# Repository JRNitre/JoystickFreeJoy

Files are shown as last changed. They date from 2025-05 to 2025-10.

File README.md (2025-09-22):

# JoystickFreeJoy

*基于 FreeJoy 固件的高精度双轴霍尔传感器 USB-HID 低成本 3D 打印摇杆方案*

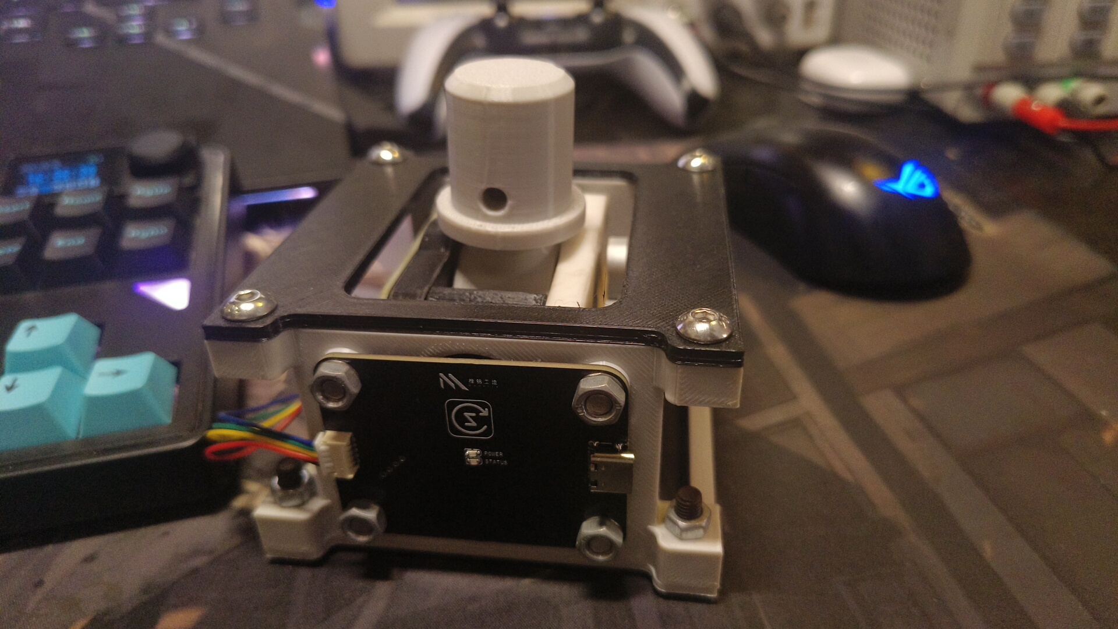
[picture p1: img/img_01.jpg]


兼顾低成本和高精度的 3D 打印摇杆方案。

# 项目特点

- 开源设计：本项目基于 MIT 协议开源，鼓励用户贡献或改进。
- 低成本：机械结构部分采用 3D 打印组件，便于制造和自定义生产。
- USB-HID：无需驱动即可实现游戏输入设备的模拟，即插即用。
- 高精度霍尔传感器：使用基于 SPI 通讯的高精度霍尔传感器 TLE5012BE100

# 许可证

本项目采用 MIT 许可证。有关详细条款，请参阅 LICENSE 文件。

# 源项目地址

本项目使用的固件和结构基于如下开源项目修改而来。

- **FreeJoy**：https://github.com/FreeJoy-Team/FreeJoy
- **底座机械结构**：https://www.thingiverse.com/thing:2496028

# 五金件

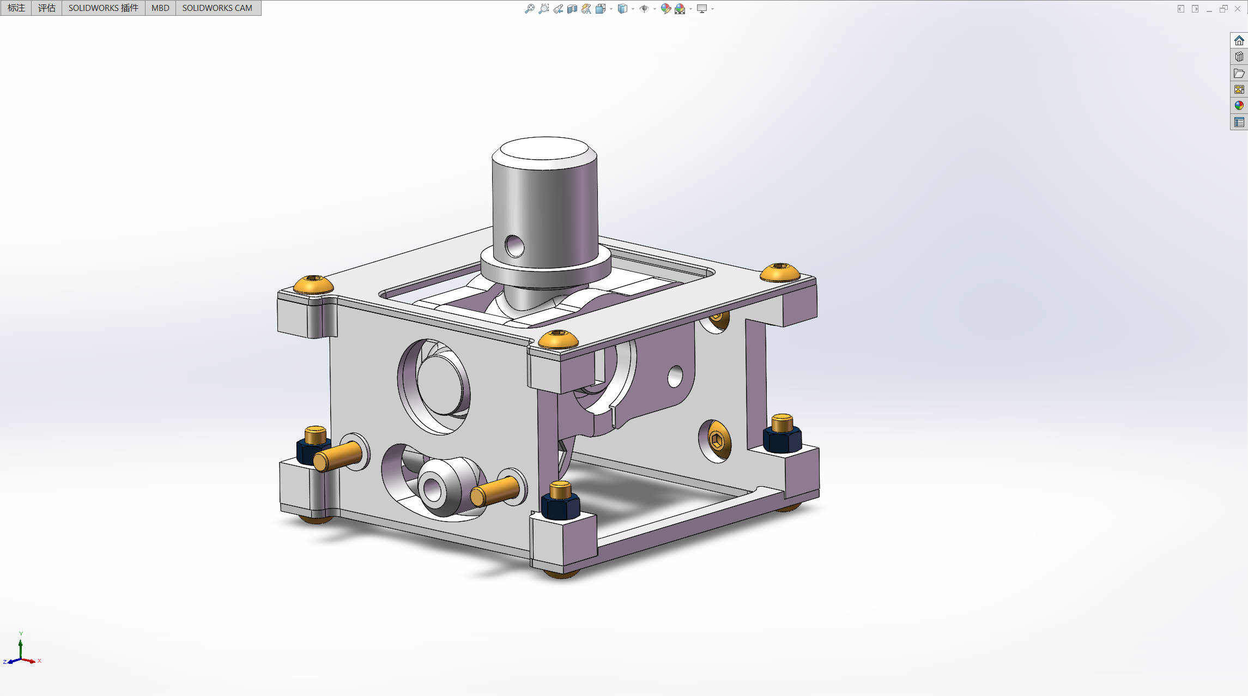
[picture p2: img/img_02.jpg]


- 深沟球轴承 6802RS [15 * 24 * 5]mm * 4
- 深沟球轴承 MR105ZZ [5 * 10 * 4]mm * 10
- M5 * 10 蘑菇头内六角螺丝 * 8
- M5 * 20 蘑菇头内六角螺丝 * 4
- M5 * 20 沉头内六角螺丝 * 4
- M5 * 35 柱头内六角螺丝 * 4
- M5 螺母 * 若干 
 
# 烧录程序

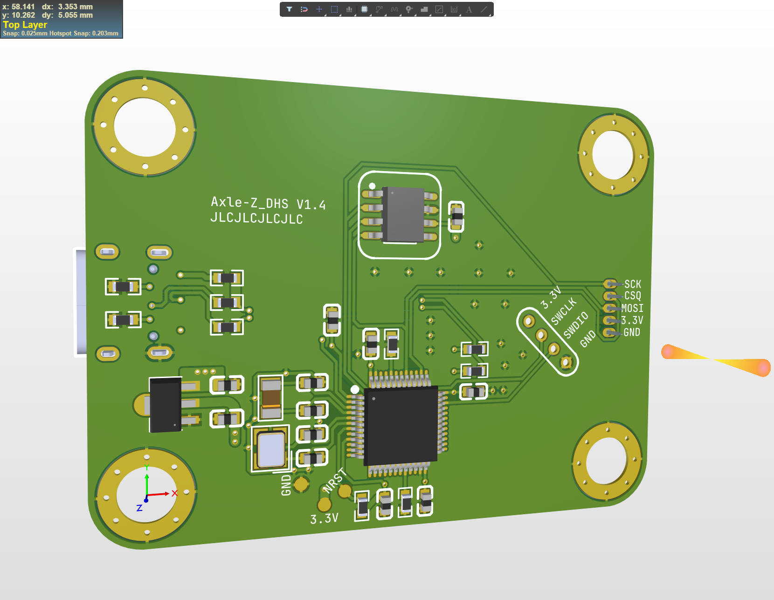
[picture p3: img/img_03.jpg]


1. 仓库提供了 freejoy 固件和 cfg 配置文件，烧录在 GUI 配置程序中导入配置文件即可使用。
2. PCB 上设计了一个使用间距 2.0mm 4P 的烧录针，通过 ST-Link Utility 烧录程序。

# 其它

1. 目前 Z 轴 (主控板) 的 PCB 基于 AD22 绘制，提供了源文件，Y 轴 PCB 基于嘉立创 EDA 绘制暂未提供源文件 (以后会转移到 AD 上提供到仓库)
2. 模型基于 Solidworks 2022 绘制，提供了源文件，后续会追加 STL 文件方便导入打印机打印。

# 项目计划

- 兼容别的杆头
- 增加 SBUS 信号输出让底座不局限于作为模拟飞行摇杆使用
- 总距杆改件
- Mini 化版本

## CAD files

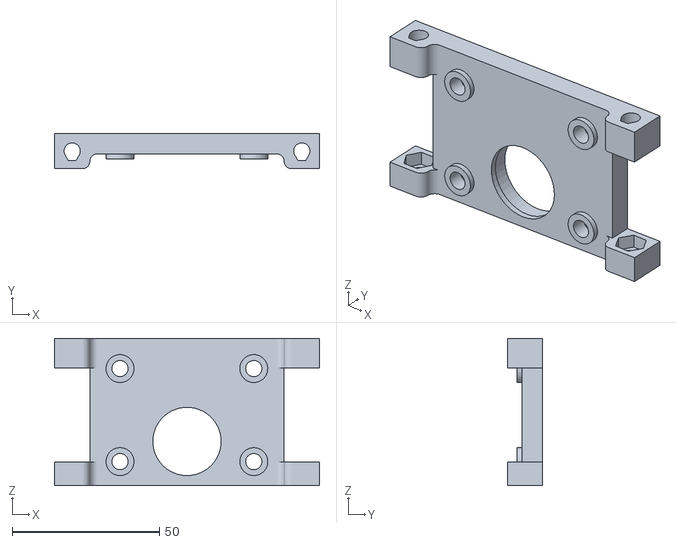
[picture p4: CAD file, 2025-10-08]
model/FDM 打印优化/joystick_base_Z-传感器板_V1.0.STL
90.0 x 12.0 x 50.0

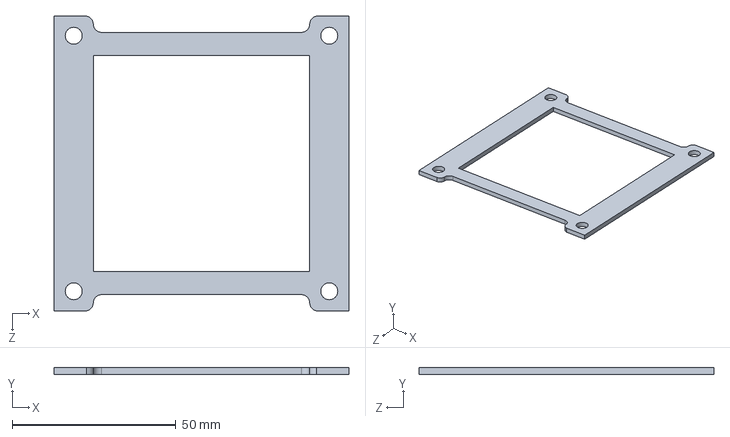
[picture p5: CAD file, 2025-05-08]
model/FDM 打印优化/solidworks2022_sldprt/joystick_base_顶板_V1.0.SLDPRT
90.0 x 2.00 x 90.0 mm

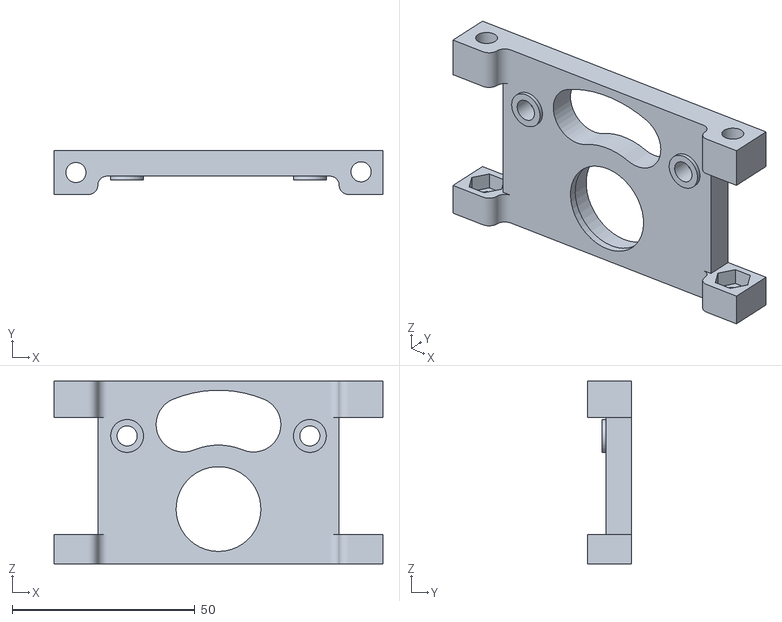
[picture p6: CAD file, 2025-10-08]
model/stand/joystick_base_stl/joystick_base_Z-钳位板_V1.0.STL
90.0 x 12.0 x 50.0

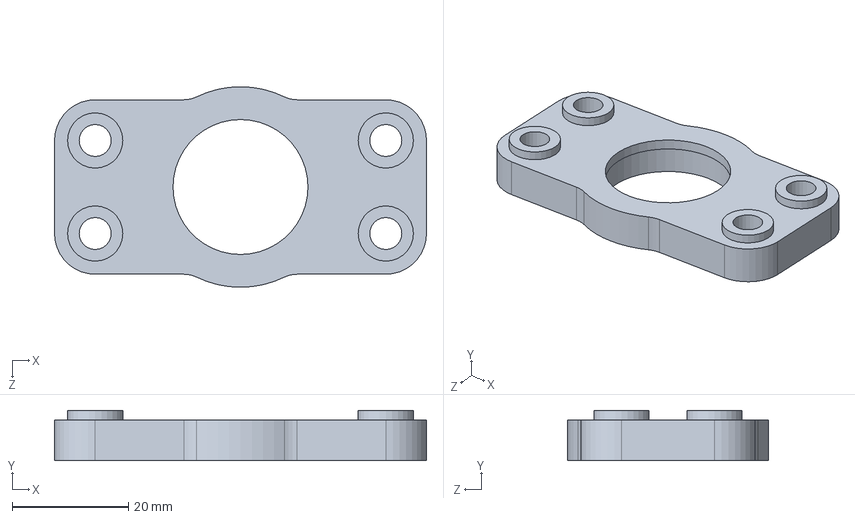
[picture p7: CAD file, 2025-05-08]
model/stand/solidworks2022_sldprt/joystick_base_Y-传感器板_V1.0.SLDPRT
64.0 x 8.65 x 34.5 mm

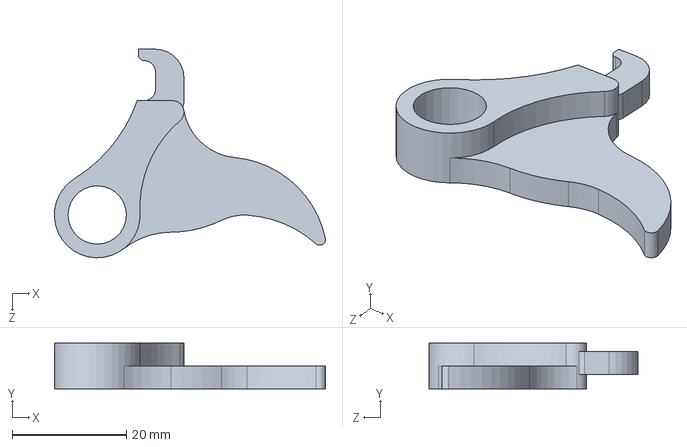
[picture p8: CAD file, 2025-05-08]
model/FDM 打印优化/solidworks2022_sldprt/joystick_base_回中组件_CNC_V1.0.SLDPRT
47.4 x 8.00 x 36.5 mm

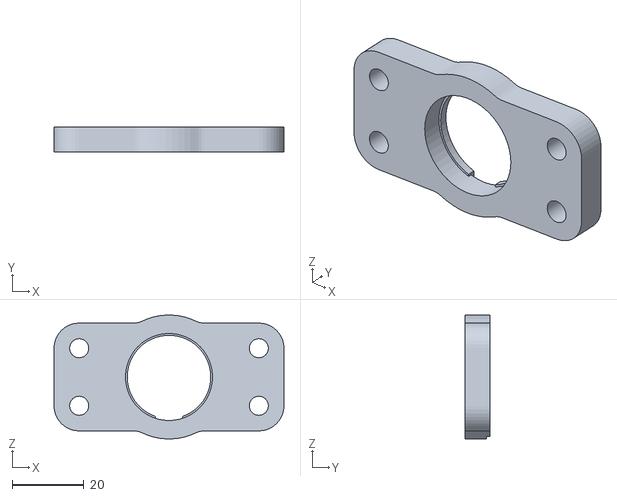
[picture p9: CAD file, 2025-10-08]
model/stand/joystick_base_stl/joystick_base_Y-传感器板_V1.0.STL
64.0 x 7.00 x 34.4

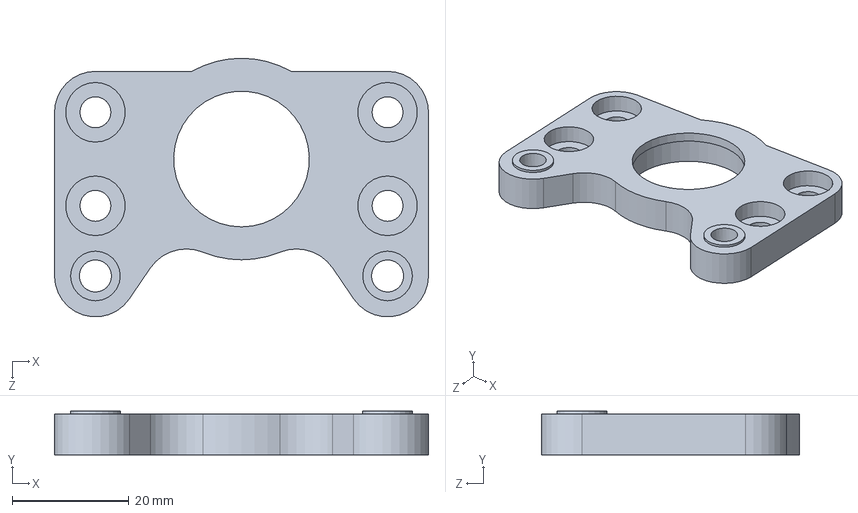
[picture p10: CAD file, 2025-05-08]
model/stand/solidworks2022_sldprt/joystick_base_Y-钳位板_V1.1.SLDPRT
64.0 x 7.50 x 44.2 mm

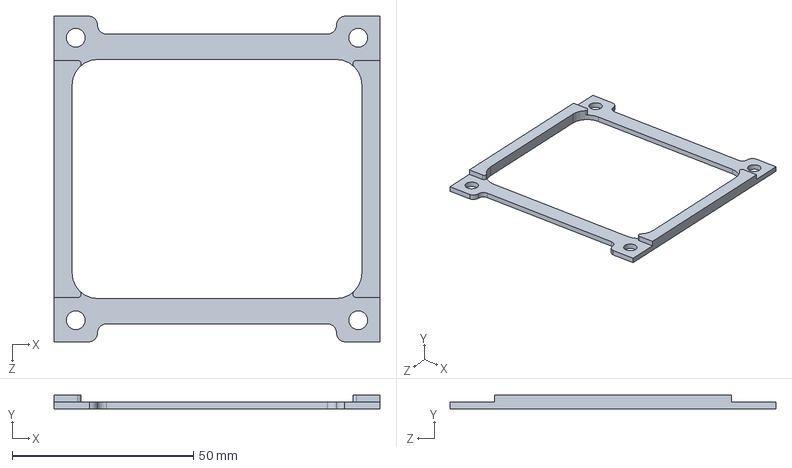
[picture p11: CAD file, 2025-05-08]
model/FDM 打印优化/solidworks2022_sldprt/joystick_base_底框_V1.1.SLDPRT
90.0 x 4.00 x 90.0 mm

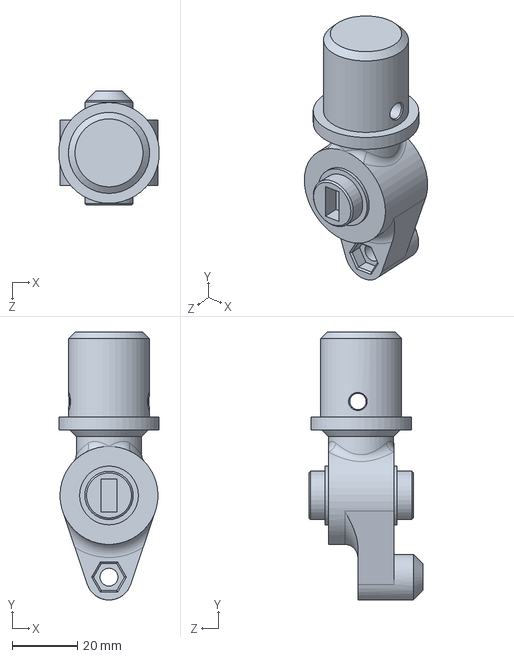
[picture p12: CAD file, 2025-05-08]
model/stand/solidworks2022_sldprt/joystick_base_摇杆座_V1.0.SLDPRT
30.7 x 82.0 x 35.0 mm

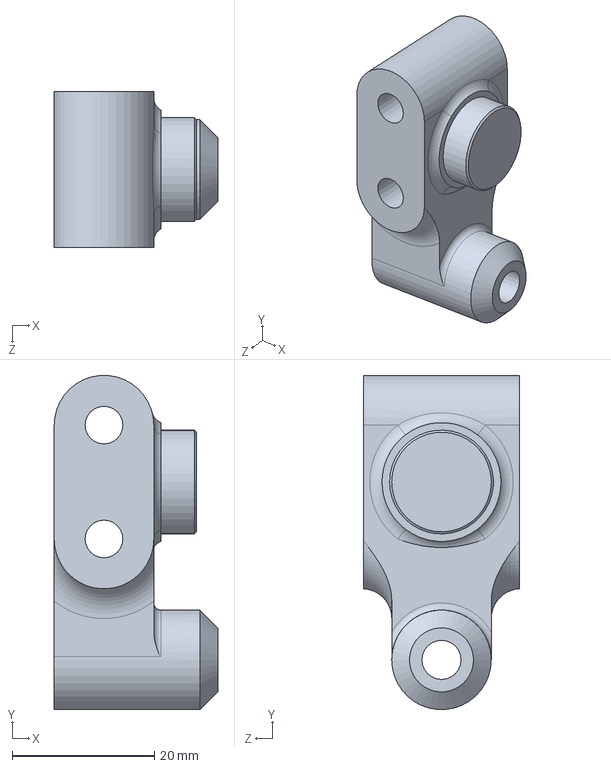
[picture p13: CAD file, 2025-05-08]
model/FDM 打印优化/solidworks2022_sldprt/joystick_base_Y-钳位固定件A_V1.1.SLDPRT
23.0 x 47.0 x 22.0 mm

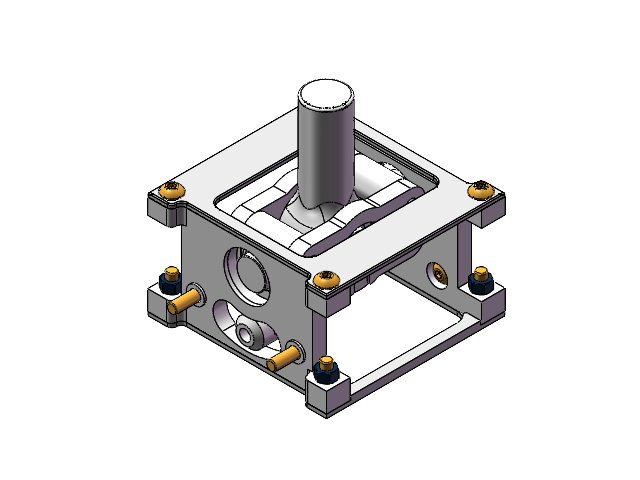
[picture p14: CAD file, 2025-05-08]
model/FDM 打印优化/solidworks2022_sldasm/JoyStick_Base.SLDASM
joystick_base_底框_V1.1
joystick_base_顶板_V1.0
joystick_base_Z-钳位板_V1.0
joystick_base_Z-传感器板_V1.0
joystick_base_Y-钳位固定件A_V1.1
joystick_base_Y-钳位固定件B_V1.0
joystick_base_Y-钳位板_V1.1
joystick_base_Y-传感器板_V1.0
joystick_base_摇杆座_V1.0
socket button head cap screw_am x 12
socket countersunk head screw_am x 2
hex nut style 1_am x 9

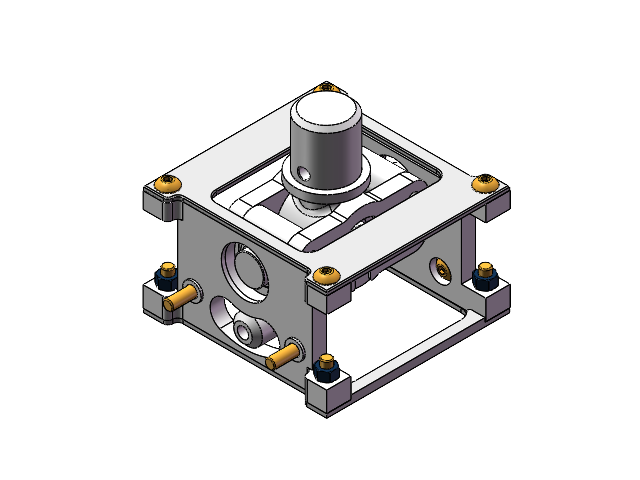
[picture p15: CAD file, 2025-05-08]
model/stand/solidworks2022_sldasm/JoyStick_Base.SLDASM
joystick_base_底框_V1.1
joystick_base_顶板_V1.0
joystick_base_Z-钳位板_V1.0
joystick_base_Z-传感器板_V1.0
joystick_base_Y-钳位固定件A_V1.1
joystick_base_Y-钳位固定件B_V1.0
joystick_base_Y-钳位板_V1.1
joystick_base_Y-传感器板_V1.0
joystick_base_摇杆座_V1.0
socket button head cap screw_am x 12
socket countersunk head screw_am x 2
hex nut style 1_am x 9

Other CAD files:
model/FDM 打印优化/joystick_base_Z-钳位板_V1.0.STL
model/stand/joystick_base_stl/joystick_base_底框_V1.1.STL
model/FDM 打印优化/solidworks2022_sldprt/joystick_base_Z-钳位板_V1.0.SLDPRT
model/stand/joystick_base_stl/joystick_base_Y-钳位板_V1.1.STL
model/stand/joystick_base_stl/joystick_base_摇杆座_V1.0.STL
model/FDM 打印优化/solidworks2022_sldprt/joystick_base_Y-钳位固定件B_V1.0.SLDPRT
model/FDM 打印优化/solidworks2022_sldprt/joystick_base_Z-传感器板_V1.0.SLDPRT
model/FDM 打印优化/solidworks2022_sldprt/joystick_base_回中组件_V1.0.SLDPRT
model/FDM 打印优化/solidworks2022_sldprt/joystick_base_摇杆座_V1.0.SLDPRT
model/stand/joystick_base_stl/joystick_base_Y-钳位固定件A_V1.1.STL
model/stand/joystick_base_stl/joystick_base_Y-钳位固定件B_V1.0.STL
model/stand/joystick_base_stl/joystick_base_Z-传感器板_V1.0.STL
model/stand/joystick_base_stl/joystick_base_顶板_V1.0.STL
model/stand/solidworks2022_sldprt/joystick_base_Y-钳位固定件B_V1.0.SLDPRT
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

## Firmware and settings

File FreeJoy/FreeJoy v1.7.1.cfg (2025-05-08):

[DeviceUsbConfig]
FirmwareVersion=1713
DeviceName=FreeJoy v1.7.1
Vid=483
Pid=5757
USBExchange=5

[PinsConfig]
A0=0
A1=0
A2=0
A3=0
A4=0
A5=0
A6=0
A7=0
A8=0
A9=0
A10=0
A15=12
B0=0
B1=0
B3=7
B4=12
B5=8
B6=10
B7=0
B8=0
B9=0
B10=0
B11=0
B12=0
B13=0
B14=0
B15=0
C13=0
C14=0
C15=0

[ShiftConfig]
Shift0=-1
Shift1=-1
Shift2=-1
Shift3=-1
Shift4=-1

[TimersConfig]
Timer1=50
Timer2=200
Timer3=300
Debounce=50
EncoderPress=30

[ButtonsConfig_0]
ButtonPhysicNumber=-1
ButtonType=0
ShiftMod=0
Inverted=0
Disabled=0
DelayTimer=0
PressTimer=0

[ButtonsConfig_1]
ButtonPhysicNumber=-1
ButtonType=0
ShiftMod=0
Inverted=0
Disabled=0
DelayTimer=0
PressTimer=0

[ButtonsConfig_2]
ButtonPhysicNumber=-1
ButtonType=0
ShiftMod=0
Inverted=0
Disabled=0
DelayTimer=0
PressTimer=0

[ButtonsConfig_3]
ButtonPhysicNumber=-1
ButtonType=0
ShiftMod=0
Inverted=0
Disabled=0
DelayTimer=0
PressTimer=0

[ButtonsConfig_4]
ButtonPhysicNumber=-1
ButtonType=0
ShiftMod=0
Inverted=0
Disabled=0
DelayTimer=0
PressTimer=0

[ButtonsConfig_5]
ButtonPhysicNumber=-1
ButtonType=0
ShiftMod=0
Inverted=0
Disabled=0
DelayTimer=0
PressTimer=0

[ButtonsConfig_6]
ButtonPhysicNumber=-1
ButtonType=0
ShiftMod=0
Inverted=0
Disabled=0
DelayTimer=0
PressTimer=0

[ButtonsConfig_7]
ButtonPhysicNumber=-1
ButtonType=0
ShiftMod=0
Inverted=0
Disabled=0
DelayTimer=0
PressTimer=0

[ButtonsConfig_8]
ButtonPhysicNumber=-1
ButtonType=0
ShiftMod=0
Inverted=0
Disabled=0
DelayTimer=0
PressTimer=0

[ButtonsConfig_9]
ButtonPhysicNumber=-1
ButtonType=0
ShiftMod=0
Inverted=0
Disabled=0
DelayTimer=0
PressTimer=0

[ButtonsConfig_10]
ButtonPhysicNumber=-1
ButtonType=0
ShiftMod=0
Inverted=0
Disabled=0
DelayTimer=0
PressTimer=0

[ButtonsConfig_11]
ButtonPhysicNumber=-1
ButtonType=0
ShiftMod=0
Inverted=0
Disabled=0
DelayTimer=0
PressTimer=0

[ButtonsConfig_12]
ButtonPhysicNumber=-1
ButtonType=0
ShiftMod=0
Inverted=0
Disabled=0
DelayTimer=0
PressTimer=0

[ButtonsConfig_13]
ButtonPhysicNumber=-1
ButtonType=0
ShiftMod=0
Inverted=0
Disabled=0
DelayTimer=0
PressTimer=0

[ButtonsConfig_14]
ButtonPhysicNumber=-1
ButtonType=0
ShiftMod=0
Inverted=0
Disabled=0
DelayTimer=0
PressTimer=0

[ButtonsConfig_15]
ButtonPhysicNumber=-1
ButtonType=0
ShiftMod=0
Inverted=0
Disabled=0
DelayTimer=0
PressTimer=0

[ButtonsConfig_16]
ButtonPhysicNumber=-1
ButtonType=0
ShiftMod=0
Inverted=0
Disabled=0
DelayTimer=0
PressTimer=0

[ButtonsConfig_17]
ButtonPhysicNumber=-1
ButtonType=0
ShiftMod=0
Inverted=0
Disabled=0
DelayTimer=0
PressTimer=0

[ButtonsConfig_18]
ButtonPhysicNumber=-1
ButtonType=0
ShiftMod=0
Inverted=0
Disabled=0
DelayTimer=0
PressTimer=0

[ButtonsConfig_19]
ButtonPhysicNumber=-1
ButtonType=0
ShiftMod=0
Inverted=0
Disabled=0
DelayTimer=0
PressTimer=0

[ButtonsConfig_20]
ButtonPhysicNumber=-1
ButtonType=0
ShiftMod=0
Inverted=0
Disabled=0
DelayTimer=0
PressTimer=0

[ButtonsConfig_21]
ButtonPhysicNumber=-1
ButtonType=0
ShiftMod=0
Inverted=0
Disabled=0
DelayTimer=0
PressTimer=0

[ButtonsConfig_22]
ButtonPhysicNumber=-1
ButtonType=0
ShiftMod=0
Inverted=0
Disabled=0
DelayTimer=0
PressTimer=0

[ButtonsConfig_23]
ButtonPhysicNumber=-1
ButtonType=0
ShiftMod=0
Inverted=0
Disabled=0
DelayTimer=0
PressTimer=0

[ButtonsConfig_24]
ButtonPhysicNumber=-1
ButtonType=0
ShiftMod=0
Inverted=0
Disabled=0
DelayTimer=0
PressTimer=0

[ButtonsConfig_25]
ButtonPhysicNumber=-1
ButtonType=0
ShiftMod=0
Inverted=0
Disabled=0
DelayTimer=0
PressTimer=0

[ButtonsConfig_26]
ButtonPhysicNumber=-1
ButtonType=0
ShiftMod=0
Inverted=0
Disabled=0
DelayTimer=0
PressTimer=0

[ButtonsConfig_27]
ButtonPhysicNumber=-1
ButtonType=0
ShiftMod=0
Inverted=0
Disabled=0
DelayTimer=0
PressTimer=0

[ButtonsConfig_28]
ButtonPhysicNumber=-1
ButtonType=0
ShiftMod=0
Inverted=0
Disabled=0
DelayTimer=0
PressTimer=0

[ButtonsConfig_29]
ButtonPhysicNumber=-1
ButtonType=0
ShiftMod=0
Inverted=0
Disabled=0
DelayTimer=0
PressTimer=0

[ButtonsConfig_30]
ButtonPhysicNumber=-1
ButtonType=0
ShiftMod=0
Inverted=0
Disabled=0
DelayTimer=0
PressTimer=0

[ButtonsConfig_31]
ButtonPhysicNumber=-1
ButtonType=0
ShiftMod=0
Inverted=0
Disabled=0
DelayTimer=0
PressTimer=0

[ButtonsConfig_32]
ButtonPhysicNumber=-1
ButtonType=0
ShiftMod=0
Inverted=0
Disabled=0
DelayTimer=0
PressTimer=0

[ButtonsConfig_33]
ButtonPhysicNumber=-1
ButtonType=0
ShiftMod=0
Inverted=0
Disabled=0
DelayTimer=0
PressTimer=0

[ButtonsConfig_34]
ButtonPhysicNumber=-1
ButtonType=0
ShiftMod=0
Inverted=0
Disabled=0
DelayTimer=0
PressTimer=0

[ButtonsConfig_35]
ButtonPhysicNumber=-1
ButtonType=0
ShiftMod=0
Inverted=0
Disabled=0
DelayTimer=0
PressTimer=0

[ButtonsConfig_36]
ButtonPhysicNumber=-1
ButtonType=0
ShiftMod=0
Inverted=0
Disabled=0
DelayTimer=0
PressTimer=0

[ButtonsConfig_37]
ButtonPhysicNumber=-1
ButtonType=0
ShiftMod=0
Inverted=0
Disabled=0
DelayTimer=0
PressTimer=0

[ButtonsConfig_38]
ButtonPhysicNumber=-1
ButtonType=0
ShiftMod=0
Inverted=0
Disabled=0
DelayTimer=0
PressTimer=0

[ButtonsConfig_39]
ButtonPhysicNumber=-1
ButtonType=0
ShiftMod=0
Inverted=0
Disabled=0
DelayTimer=0
PressTimer=0
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

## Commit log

2025-05-08 添加文件，编写 README
    [FreeJoy v1.7.1.cfg, JoyStick_Base.SLDASM, PCB.PcbDoc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]
2025-05-28 完善 README
2025-06-12 b友指正 BOM 轴承数量问题
2025-06-29 修改 README 文档
2025-09-22 增加了 y 轴 pcb 设计文件（立创edapro版本）
2025-10-08 增加了 stl 文件
    [joystick_base_Y-传感器板_V1.0.STL, joystick_base_Y-钳位固定件A_V1.1.STL, joystick_base_Y-钳位固定件B_V1.0.STL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]
2025-10-08 增加了针对 fdm 打印的 stl 文件
    [joystick_base_Z-传感器板_V1.0.STL, joystick_base_Z-钳位板_V1.0.STL]
